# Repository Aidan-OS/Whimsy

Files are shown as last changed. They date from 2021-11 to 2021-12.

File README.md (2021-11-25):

# Whimsy - Rev0.5

### Description

Hi, I'm Aidan and I have at least temporarily started working on the Whimsy after it seems like Prkns has abandoned it. As of writing this, Prkns has been inactive on discord for about 4 months with DSA 1930 not being shipped even though it should have been received.

All that I have done is from revision 4 and beyond. I am currently making the Whimsy for myself, but should Prkns not return I will run a group buy on my own. I can confirm that the rev 4 PCB is working, however the rev 4 plate is not. Rev 5 plate will work for sure.

The case files can be found in the corresponding file. The 3D print file is not currently up to date as I will need to mirror changes from the CNC version to it.

### Plans 🤔

**rev1:** A working version of the board and an FR4 sandwich case

**rev2:** Tidied up traces and an acrylic case

**rev3:** Prepared for group buy (Prkns went missing at this point)

**rev4:** Fixed issues with OLED connections, added a reset button (Tested and Functional). Uploaded case and plate, both still need some work.

**rev5:** Added compatibility for Nice!Nano (UNTESTED), fixed stupid button position

---

**OLD DESCRIPTION**

A 40% keyboard with exposed Elite-C/OLED and Rotary encoder.

My first attempt at designing a "proper" custom keyboard. I spent far too long looking at all the amazing new PCB's and custom keyboards being released and having a massive urge to do one for myself. Here is my first attempt.

I've not taken delivery of the physical PCBs as of yet so i can't comment on how well i did, but they will be with me shortly.

**STILL IN DEVELOPMENT - NOT READY FOR PRODUCTION - DO NOT ORDER**

Whimsy

Whimsy

#### Say hi 👋

If you're interested in any aspect of this board or want to point out anything that could be done better in a more private manner, head on over to my [website](https://prkns.me/) and you'll find a few different methods on there.

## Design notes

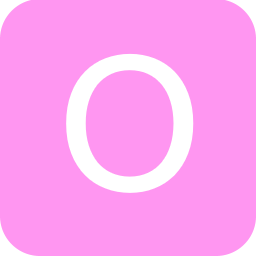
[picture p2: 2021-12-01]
Images/Discord Emotes/Whoopsy_O1.png

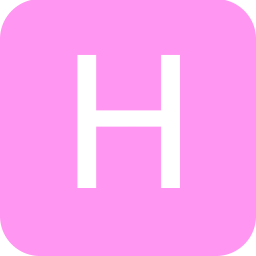
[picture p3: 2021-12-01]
Images/Discord Emotes/Whoopsy_H.png

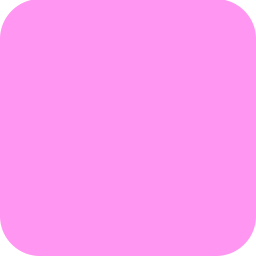
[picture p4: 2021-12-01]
Images/Discord Emotes/Blank Emote.png

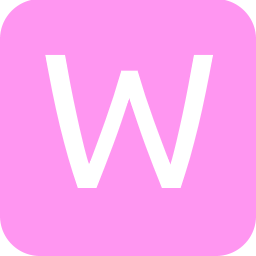
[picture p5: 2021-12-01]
Images/Discord Emotes/Whoopsy_W.png

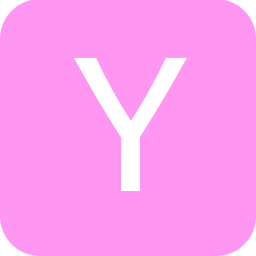
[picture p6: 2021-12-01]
Images/Discord Emotes/Whoopsy_Y.png

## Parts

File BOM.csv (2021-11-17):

Needed from this repo
Item | Count | Note | Link
PCB | 1 |  | https://github.com/Aidan-OS/Whimsy/tree/master/PCB
Plate | 1 |  | https://github.com/Aidan-OS/Whimsy/tree/master/Plate
Case | 1 |  | https://github.com/Aidan-OS/Whimsy/tree/master/Case
Keebio Order
Item | Count | Note | Link
M2 Standoff (9mm) | 4 |  | https://keeb.io/products/m2-screws-and-standoffs
Reset Swtich | 1 |  | https://keeb.io/products/reset-pushbutton-switch
1N4148 Diodes - Through Hole | 50 |  | https://keeb.io/products/1n4148-diodes
EC11 Rotary Encoder | 1 |  | https://keeb.io/products/rotary-encoder-ec11
Elite-C | 1 | Optional-replace with Nice!Nano | https://keeb.io/products/elite-c-low-profile-version-usb-c-pro-micro-replacement-atmega32u4
Nice Keyboards Order
Item | Count | Note | Link
Nice!Nano | 1 | Optional - Bluteooth Elite-C replacement | https://nicekeyboards.com/nice-nano/
McMaster-Carr Order
Item | Count | Note | Link
M2 3mm Screw | 5 |  | https://www.mcmaster.com/91290A010/
M2 16mm Screw | 4 |  | https://www.mcmaster.com/91290A047/
M2 heat set inserts | 9 | Optional - 3D print only | https://www.mcmaster.com/94459A110/
Sparkfun Order
Item | Count | Note | Link
JST Connector | 1 | Optional - Only needed with Nice!Nano | https://www.sparkfun.com/products/9749
Lithium Ion Battery | 1 | Optional - Only needed with Nice!Nano | https://www.sparkfun.com/products/18286
OLED options (Available from many places)
Option 1: | SSD1306 OLED 128x32
Option 2: | SSD1306 OLED 128x64

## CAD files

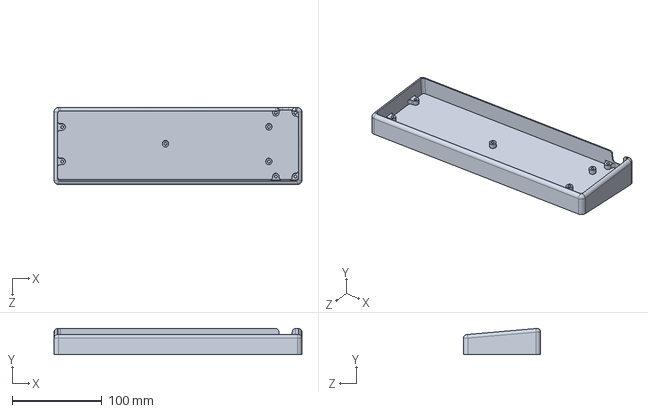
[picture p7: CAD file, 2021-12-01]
Case/Case (3D Printable).SLDPRT
276.7 x 29.2 x 86.2 mm

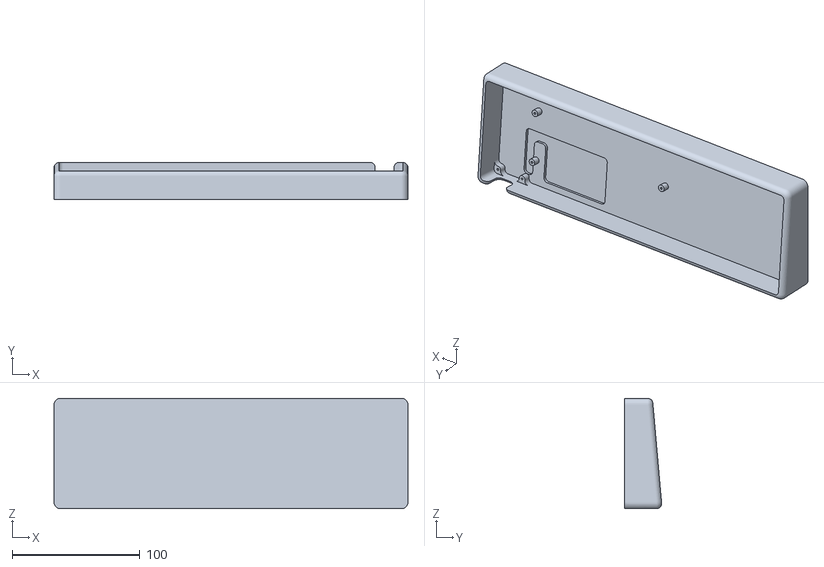
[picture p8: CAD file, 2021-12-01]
Case/Output Files/Case (CNC).STL
276.7 x 29.2 x 86.2

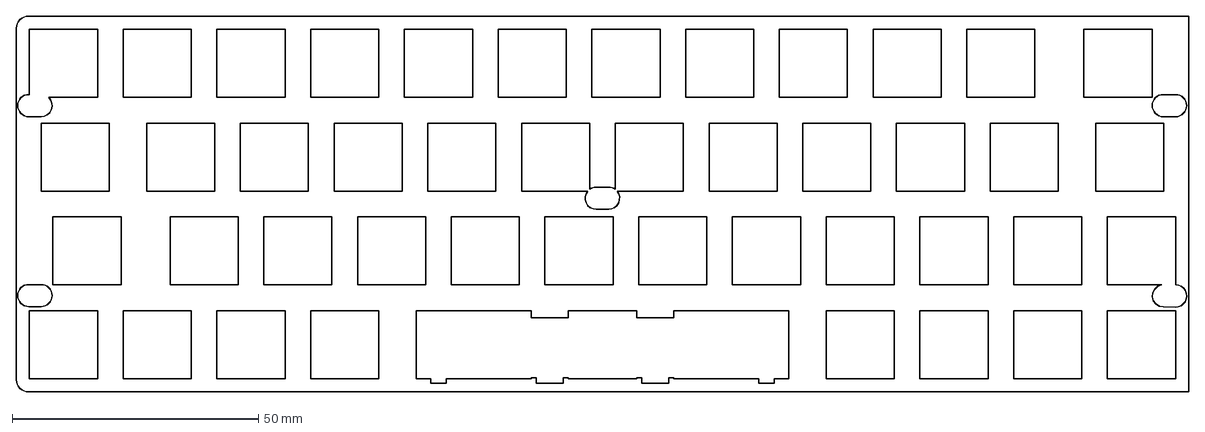
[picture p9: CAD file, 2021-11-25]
Plate/Whimsy Plate (Holes).dxf
238.3 x 76.4 mm

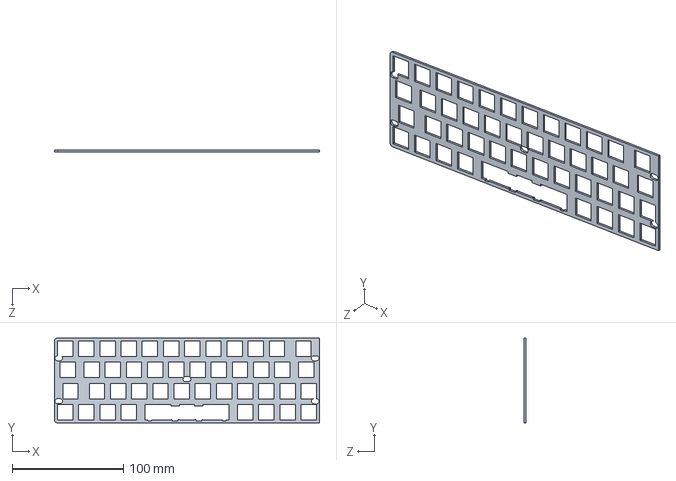
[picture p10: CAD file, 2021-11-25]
Plate/Plate Solidworks.SLDPRT
238.3 x 76.4 x 1.60 mm

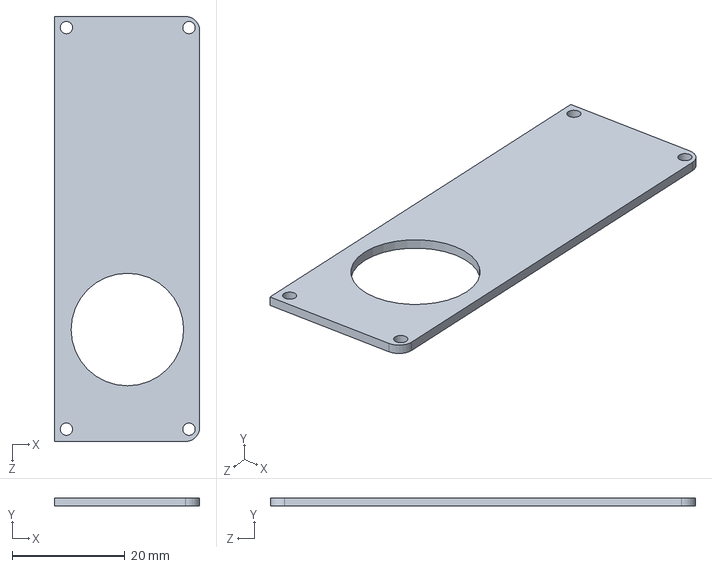
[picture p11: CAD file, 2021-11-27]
Case/Acrylic Cover.SLDPRT
25.8 x 1.50 x 75.5 mm

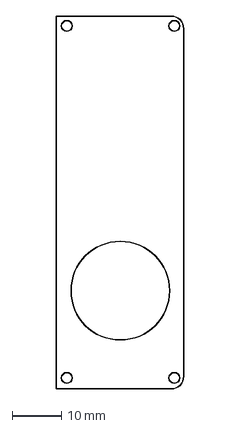
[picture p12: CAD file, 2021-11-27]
Case/Output Files/Acrylic Cover.DXF
25.8 x 75.5 mm

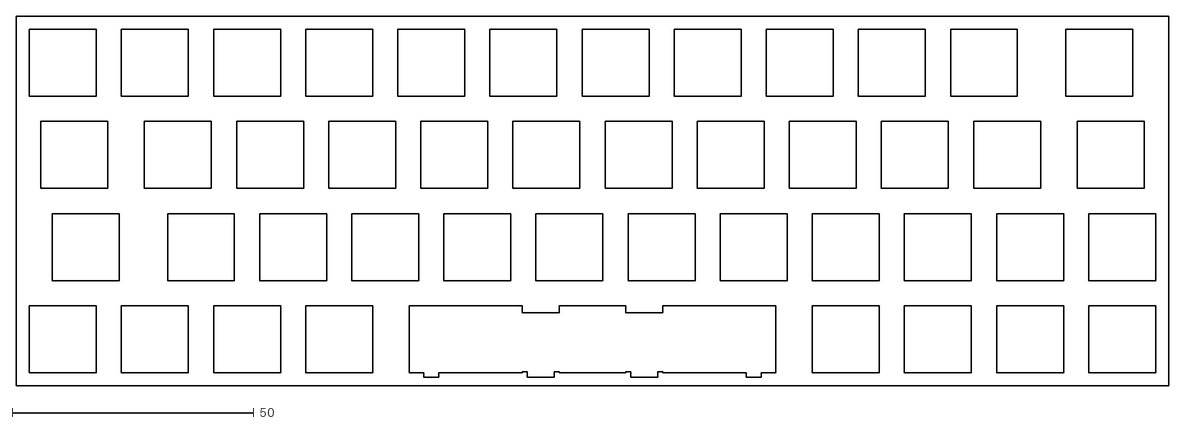
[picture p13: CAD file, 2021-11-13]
Plate/Whimsy Plate (No Holes).dxf
238.3 x 76.4

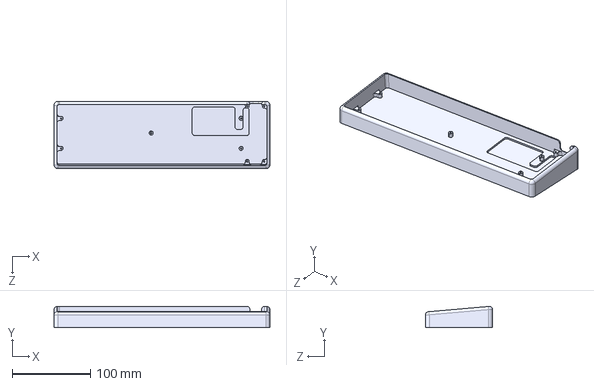
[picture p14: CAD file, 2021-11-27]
Case/Case AP214.STEP
276.7 x 27.2 x 86.2 mm

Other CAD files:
Case/Case.SLDPRT
Case/Output Files/Case (3D Printable).STL
Case/Case AP203.STEP

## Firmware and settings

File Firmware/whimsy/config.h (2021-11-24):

#ifndef CONFIG_H
#define CONFIG_H

#include "config_common.h"

/* USB Device descriptor parameter */
#define VENDOR_ID       0xFEED
#define PRODUCT_ID      0x6060
#define DEVICE_VER      0x0001
#define MANUFACTURER    Aidan
#define PRODUCT         Whomsy
#define DESCRIPTION     A Whomsical 40%

/* key matrix size */
#define MATRIX_ROWS 8
#define MATRIX_COLS 6

#define ENCODER_RESOLUTION 2
#define ENCODERS_PAD_A { D5 }
#define ENCODERS_PAD_B { B7 }

/* key matrix pins */
#define MATRIX_ROW_PINS { F5, F6, B2, B5, F4, D4, B4, B6 }
#define MATRIX_COL_PINS { B3, E6, B1, D7, F7, C6 }
#define UNUSED_PINS

/* COL2ROW or ROW2COL */
#define DIODE_DIRECTION COL2ROW

#define OLED_DISPLAY_128X64 //Comment this out to change the screen size

/* number of backlight levels */

#ifdef BACKLIGHT_PIN
#define BACKLIGHT_LEVELS 3
#endif

/* Set 0 if debouncing isn't needed */
#define DEBOUNCING_DELAY 5

/* Mechanical locking support. Use KC_LCAP, KC_LNUM or KC_LSCR instead in keymap */
#define LOCKING_SUPPORT_ENABLE

/* Locking resynchronize hack */
#define LOCKING_RESYNC_ENABLE

/* key combination for command */
#define IS_COMMAND() ( \
    keyboard_report->mods == (MOD_BIT(KC_LSHIFT) | MOD_BIT(KC_RSHIFT)) \
)

/* prevent stuck modifiers */
#define PREVENT_STUCK_MODIFIERS

#define RGB_DI_PIN C7
#ifdef RGB_DI_PIN
#define RGBLIGHT_ANIMATIONS
#define RGBLED_NUM 8
#define RGBLIGHT_HUE_STEP 8
#define RGBLIGHT_SAT_STEP 8
#define RGBLIGHT_VAL_STEP 8
#endif

#endif

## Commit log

2021-11-13 Committing all the work I have done recently
    [Case.SLDPRT, Plate Solidworks.SLDPRT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]
2021-11-14 Added 3D print designed case, Fixed Platefile to accomidate screw head, added BOM
    [BOM.csv, Case (3D Printable).SLDPRT, Case (3D Printable).STL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]
2021-11-17 Revised BOM to add mention of the OLEDs
    [BOM.csv]
2021-11-24 Updated firmware to work with newer versions of QMK
    [Case (CNC).STL, Case.SLDPRT]
2021-11-25 Revised case to make room for battery and deal with KAM/KAT clearance issues. Increased size of holes on plate to deal with screw clearlance issues. Moved reset button to place it in a more reasonabl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
2021-11-27 Updated the firmware to show what layer you are on instead of my logo
    [Acrylic Cover.DXF, Acrylic Cover.SLDPRT, Case AP203.STEP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]
2021-12-01 Various small updates, brought 3D model more in line with CNC model. Can't really test the fit for the JST connector currently
    [Acrylic Cover.DXF, Case (3D Printable).SLDPRT, Case (3D Printable).STL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]
